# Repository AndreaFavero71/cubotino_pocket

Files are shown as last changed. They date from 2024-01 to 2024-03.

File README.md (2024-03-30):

# CUBOTino Pocket

This repo contains the relevant files for ....

How to make CUBOTino Pocket: A small, 3D printed, optimal solver for 2x2x2 Rubik's cube
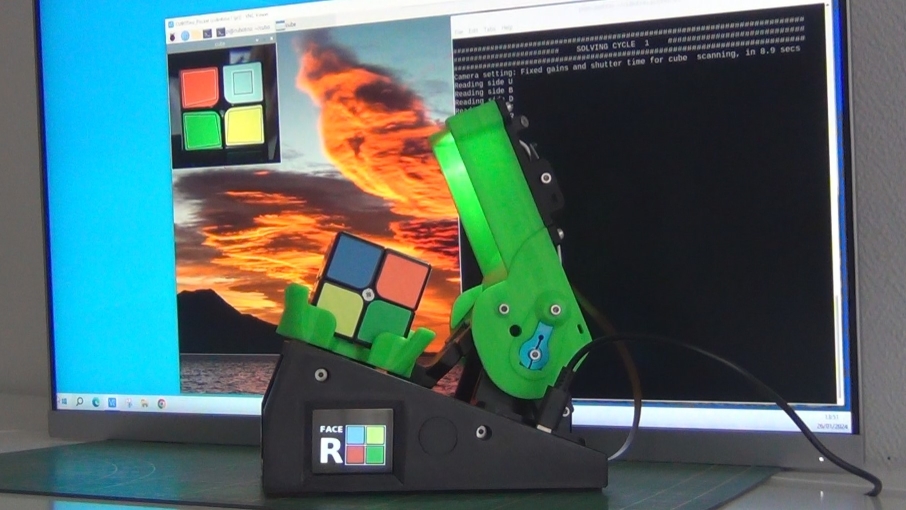
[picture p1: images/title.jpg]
title image


Further robot info at: https://www.instructables.com/CUBOTino-Pocket-Optimal-Solver-Robot-for-Rubiks-Cu/

An impression of the robot: https://youtu.be/wB4MwINGon0

This git repo simplifies the download of the individual files and automates as much a possible the deployment to the Raspberry Pi

This installation has proved to work on different Raspberry Pi models; Please report in case you experience issues.

# How to use it:
1. Flash your SD card according to the procedure in the [document here](doc/How_to_make_CUBOTino_Pocket_20240329.pdf) , Chapter 7, Step1 to Step3
2. Put the sd card in the pi and power it. You can monitor the boot process if you connect an hdmi monitor to it but it is not essential. 
3. Try to connect to the Raspberry Pi via SSH. On Windows you can use Putty. On linux and mac you can type directly:
```
ssh pi@cubotino.local
```
4. If you can't reach the pi like this, you will have to scan your network to find the IP to use
5. After you are connected via ssh, type the following commands in the shell:
```
git clone https://github.com/AndreaFavero71/cubotino_pocket.git
cd cubotino_pocket/src
chmod +x install/setup.sh
sudo ./install/setup.sh
```
6. Make sure the script runs without error until the end. It should ask you to reboot. Type 'y' and hit enter.
7. If the question "Reboot (y/n)" does't appear, them the installation is facing issues; Try to fix the errors, and run the script again.
8. If the question "Reboot (y/n) does appear, You should get the proper environment after the reboot.

# Build the robot:
Follow the instructions (saved at /doc folder)

# Tuning the servos position via GUI (via VNC):
```
cd ~/cubotino_pocket/src
source .virtualenvs/bin/activate
python Cubotino_P_GUI.py
```
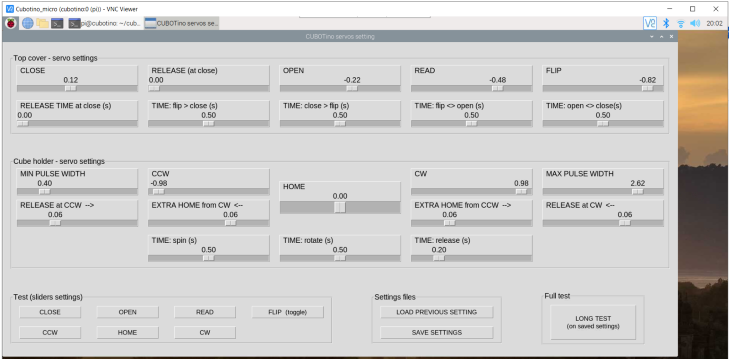
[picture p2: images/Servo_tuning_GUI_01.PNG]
title image


# Executing manually
From a shell, you can run the main python script like this:
```
cd ~/cubotino_pocket/src
source .virtualenvs/bin/activate
python Cubotino_P.py
```
of course, you can replace `Cubotino_P.py` by any other python scripts as mentioned in the documentation.

# Enabling autostart
When everything is tuned and you want to autostart the software automatically on reboot, just type :
```
    sudo crontab -e
```
select the nano editor '1' then go to the last line of the window and remove the first '#' character of the line . This uncomment the startup script that launches cubotino on startup. You can reboot after to test it.

# VNC connection
You can always connect with ssh. If you prefere VNC you can download the RealVNC client (this is the one I use). You just have that start it like this:
```
vncviewer cubotino.local
```
It will ask for the credential. Use 'pi' and the same password you use for ssh. You should have a desktop version in this way

Check out the "How_to_make ...  .pdf" document (at /doc folder) for further info.<br /><br />

# Please leave a feedback if you build it
I hope many of you will decide to build your own CUBOTino, and that you'll enjoy it as much much as I did. <br />
I hope you will also post an "I Made it", on the Instructables site of this project (link above); <br />
I can ensure you, seeing a new born CUBOTino makes me feel very well 🙂

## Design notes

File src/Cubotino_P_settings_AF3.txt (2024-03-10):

{
"frameless_cube": "auto",
"disp_width": "130",
"disp_height": "160",
"disp_offsetL": "-2",
"disp_offsetT": "0",
"camera_width_res": "640",
"camera_hight_res": "480",
"s_mode": "7",
"kl": "0.95",
"expo_shift": "-1.0",
"x_l": "46",
"x_r": "82",
"y_u": "32",
"y_b": "78",
"warp_fraction": "6.2",
"warp_slicing": "2.0",
"square_ratio": "1",
"rhombus_ratio": "0.3",
"delta_area_limit": "0.7",
"collage_w": "1024",
"marg_coef": "0.05",
"cam_led_bright": "0.1",
"detect_timeout": "40",
"show_time": "7",
"warn_time": "1.5",
"quit_time": "4.5",
"cover_self_close": "true",
"vnc_delay": "0.0",
"built_by": "",
"built_by_x": "25",
"built_by_fs": "16",
"fcs_delay": "3"
}

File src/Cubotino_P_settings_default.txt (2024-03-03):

{
"frameless_cube": "auto",
"disp_width": "130",
"disp_height": "160",
"disp_offsetL": "0",
"disp_offsetT": "0",
"camera_width_res": "640",
"camera_hight_res": "480",
"s_mode": "7",
"kl": "0.95",
"expo_shift": "-0.6",
"x_l": "0",
"x_r": "0",
"y_u": "0",
"y_b": "0",
"warp_fraction": "7",
"warp_slicing": "1.5",
"square_ratio": "1",
"rhombus_ratio": "0.3",
"delta_area_limit": "0.7",
"collage_w": "1024",
"marg_coef": "0.1",
"cam_led_bright": "0.1",
"detect_timeout": "40",
"show_time": "7",
"warn_time": "1.5",
"quit_time": "4.0",
"cover_self_close": "true",
"vnc_delay": "0.5",
"built_by": "",
"built_by_x": "25",
"built_by_fs": "16",
"fcs_delay": "3"
}

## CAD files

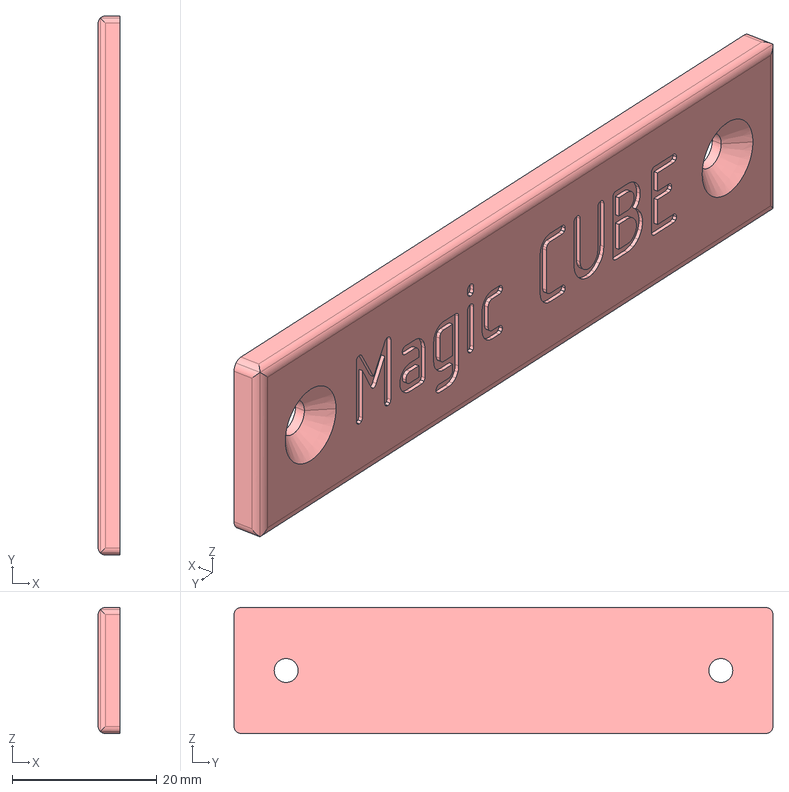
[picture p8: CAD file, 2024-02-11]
stp/Personaliz_plate_01.stp
3.00 x 74.4 x 17.4 mm

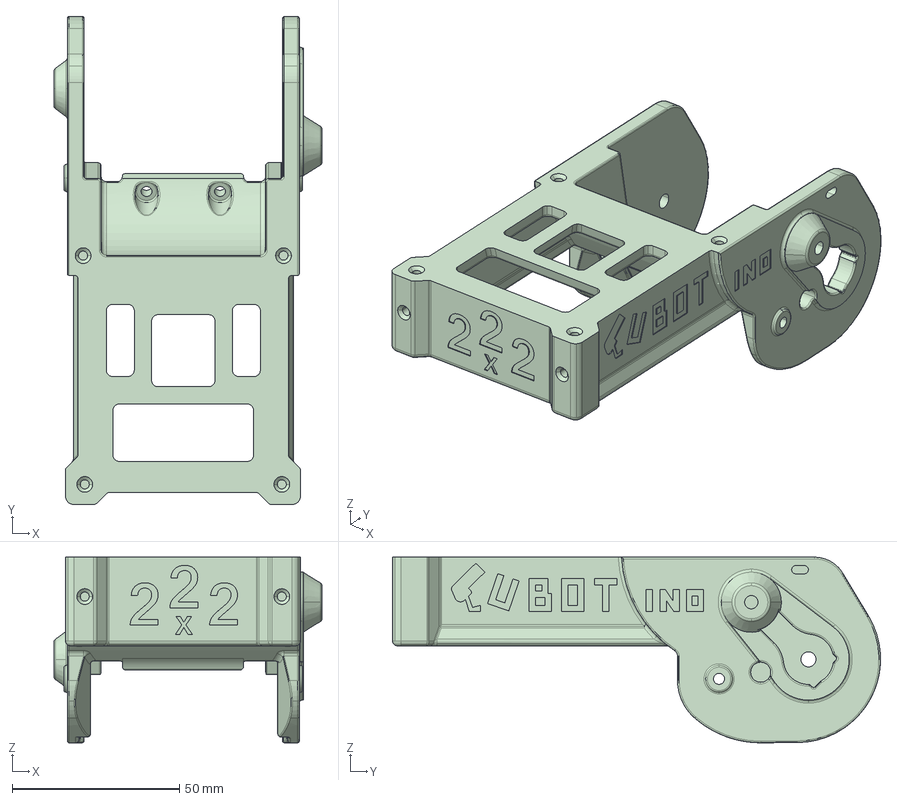
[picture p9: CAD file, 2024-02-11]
stp/Top_cover_pocket.stp
80.2 x 146.1 x 55.6 mm

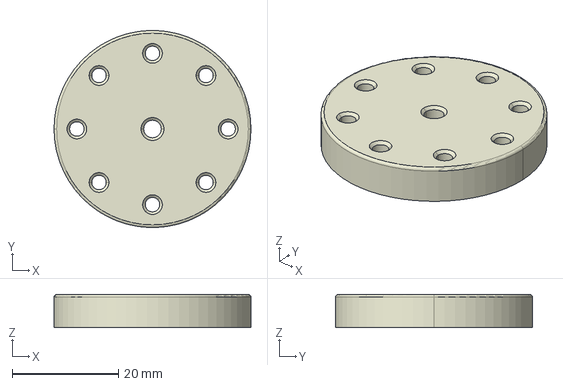
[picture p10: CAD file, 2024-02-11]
stp/Alternative_Servo_axis_sup_pocket.stp
37.0 x 37.0 x 6.20 mm

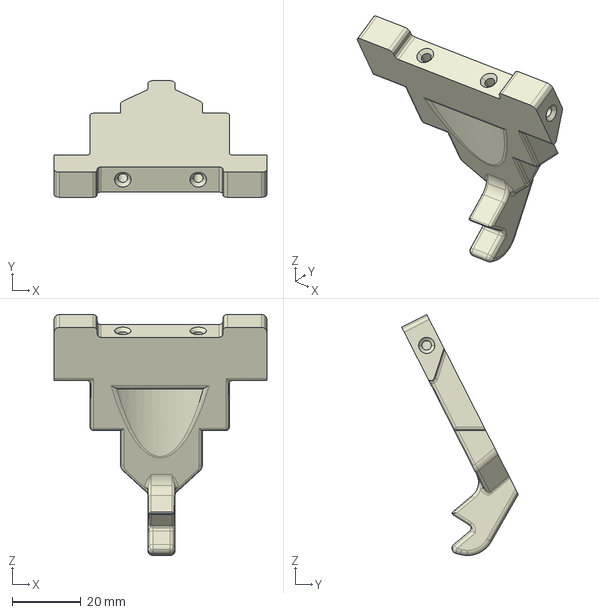
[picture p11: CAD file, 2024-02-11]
stp/Cube_lifter.stp
62.0 x 34.0 x 70.3 mm

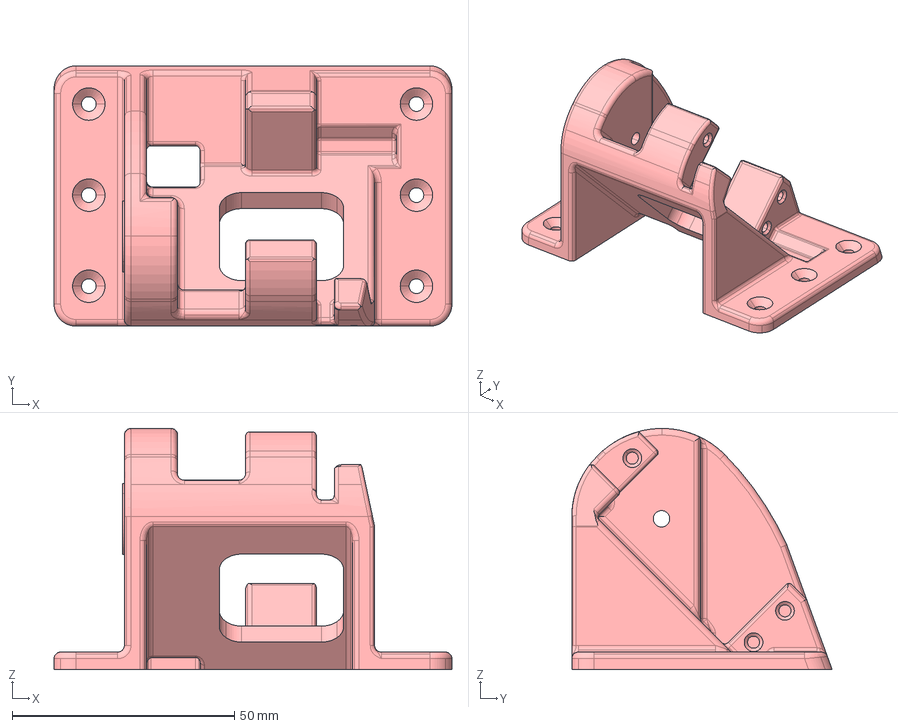
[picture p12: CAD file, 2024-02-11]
stp/Hinge_pocket.stp
89.6 x 58.6 x 54.3 mm

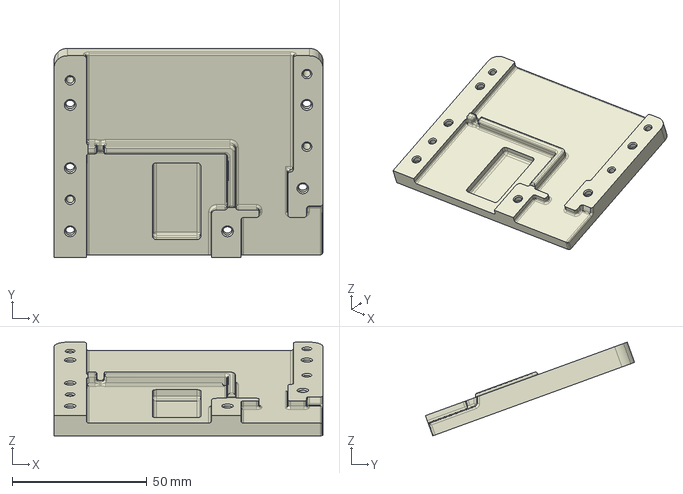
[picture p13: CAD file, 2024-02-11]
stp/Baseplate_rear.stp
100.0 x 77.8 x 34.8 mm

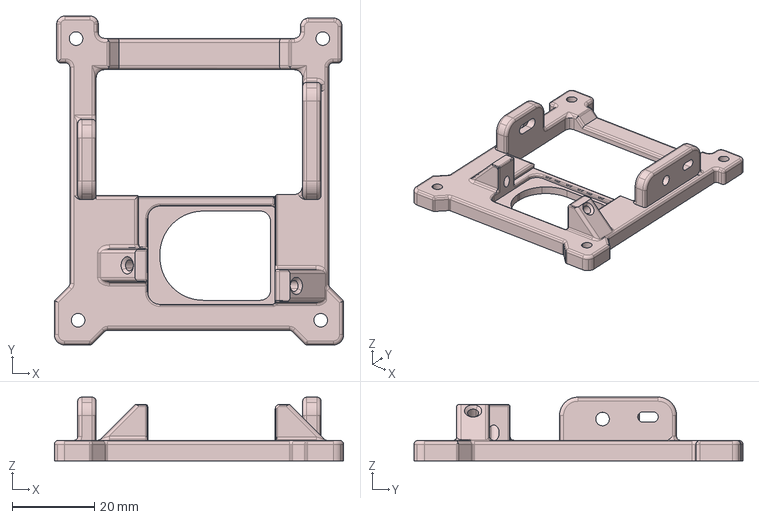
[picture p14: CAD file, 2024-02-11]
stp/PiCamera_holder_frame_pocket.stp
70.3 x 80.0 x 15.5 mm

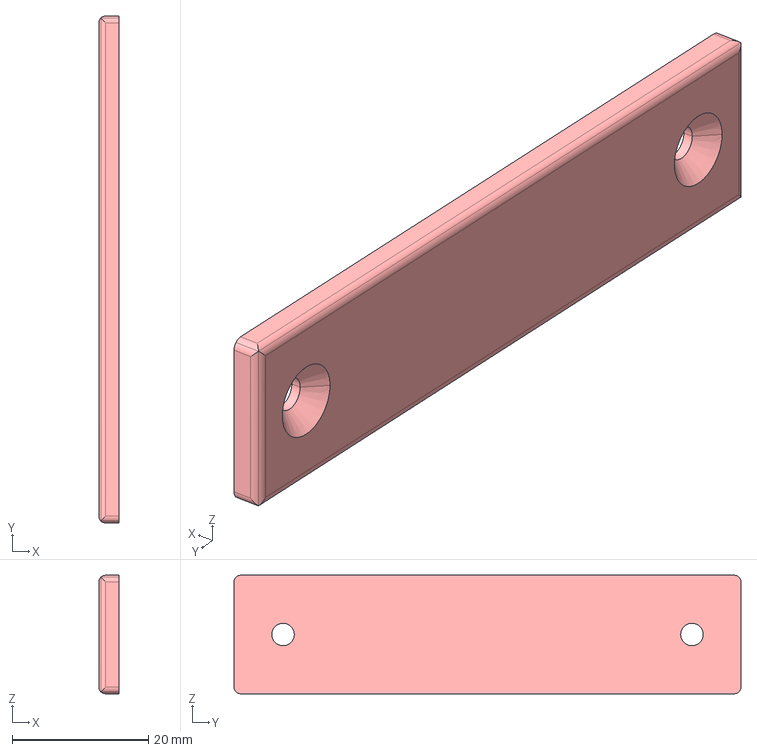
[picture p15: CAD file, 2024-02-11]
stp/Personaliz_plate.stp
3.00 x 74.4 x 17.4 mm

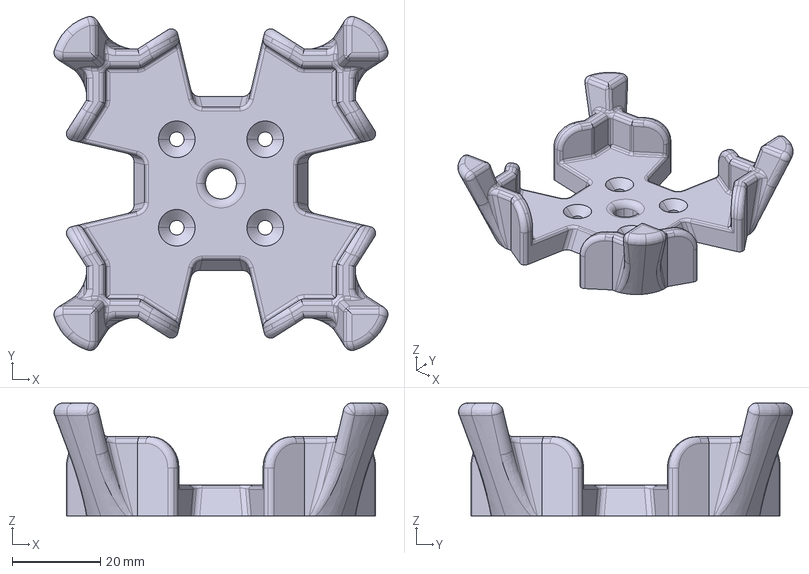
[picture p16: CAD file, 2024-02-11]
stp/Cube_holder_pocket.stp
75.9 x 75.9 x 25.7 mm

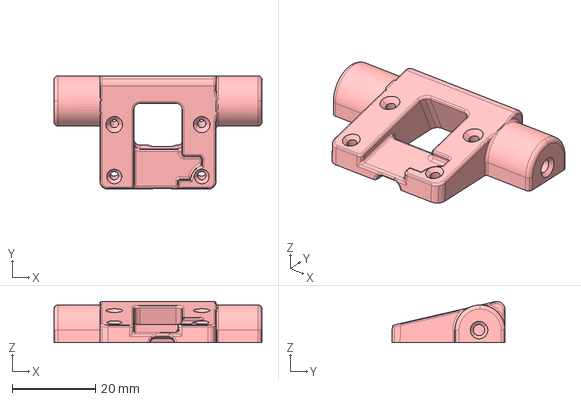
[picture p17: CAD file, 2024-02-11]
stp/PiCamera_holder_step.stp
50.0 x 27.3 x 9.88 mm

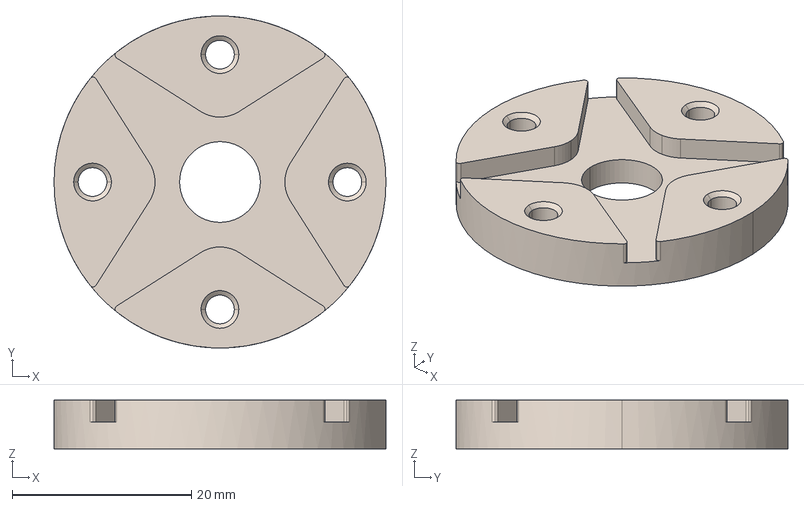
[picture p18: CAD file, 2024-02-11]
stp/Servo_axis_inf_pocket.stp
37.0 x 37.0 x 5.44 mm

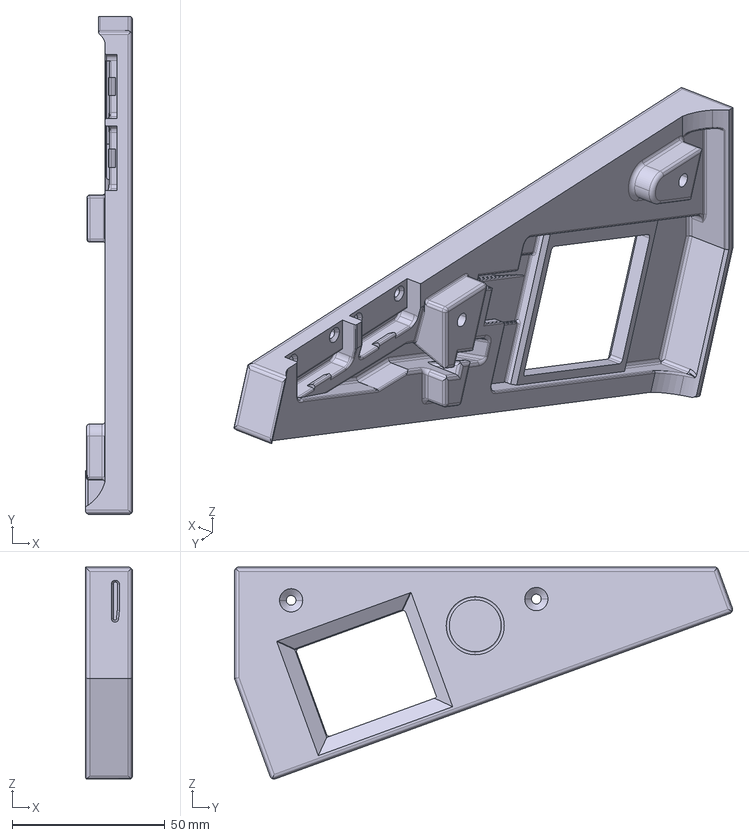
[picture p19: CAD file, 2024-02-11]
stp/PCB_cover_display_rev1.stp
15.5 x 163.0 x 69.4 mm

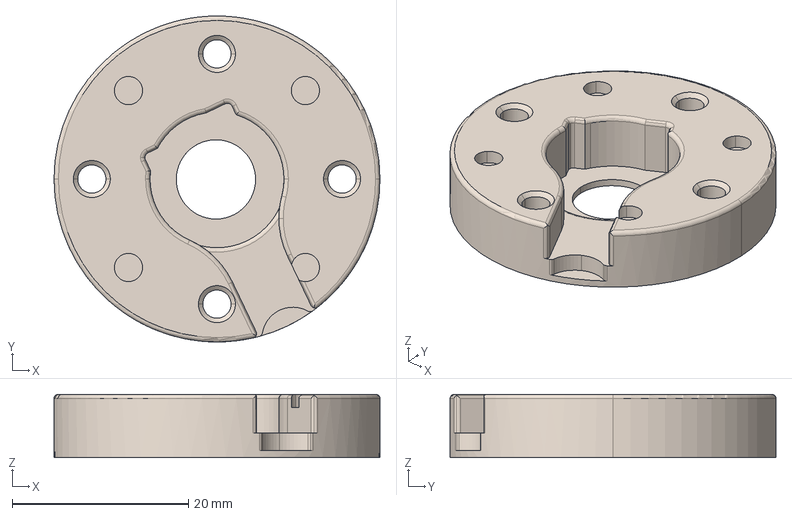
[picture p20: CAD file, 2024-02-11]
stp/Alternative_Servo_axis_inf_pocket.stp
37.0 x 37.0 x 7.20 mm

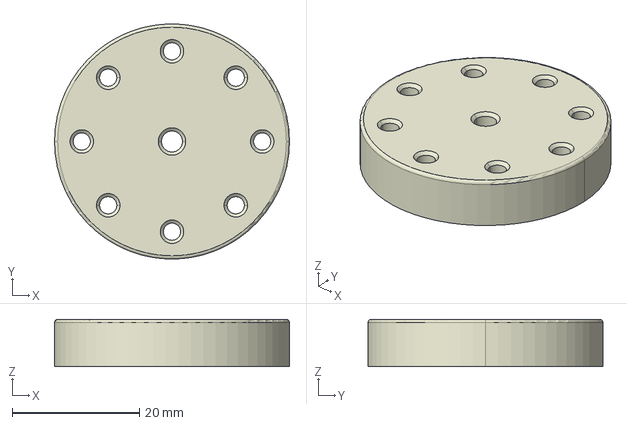
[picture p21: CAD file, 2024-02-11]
stp/Servo_axis_sup_pocket.stp
37.0 x 37.0 x 7.46 mm

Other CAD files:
stp/Structure_pocket.stp
stp/Baseplate_front.stp
stp/PCB_cover_display_UsbC.stp
stl/Alternative_Servo_axis_inf_pocket..stl
stl/Alternative_Servo_axis_sup_pocket..stl
stl/Baseplate_rear.stl
stl/Cube_lifter.stl
stl/Personaliz_plate.stl
stl/Personaliz_plate_01.stl
stl/Servo_axis_inf_pocket..stl
stl/Servo_axis_sup_pocket..stl

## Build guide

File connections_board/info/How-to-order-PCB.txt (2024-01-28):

How to Order PCB

Please refer to:
https://docs.easyeda.com/en/PCB/Order-PCB

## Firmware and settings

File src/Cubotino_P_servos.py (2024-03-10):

#!/usr/bin/python
# coding: utf-8

"""
#############################################################################################################
# Andrea Favero, 10 March 2024
#
# This code relates to CUBOTino Pocket, a very small and simple Rubik's cube solver robot 3D printed.
# CUBOTino_P is the autonomous version of the CUBOTino robot series, for the 2x2x2 Rubik's cube.
# This specific script controls two servos based on the movements string from Cubotino_P.py
# 
# Possible moves with this robot
# 1) Spins the complete cube ("S") laying on the bottom face: 1 means CW 90deg turns, while 3 means 90CCW turn
# 2) Flips the complete cube ("F") by "moving" the Front face to Bottom face: Only positive values are possible
# 3) Rotates the bottom layer ("R") while costraining the 2nd and 3rd layer.
# 4) The order of S, F has to be strictly followed
# 5) Example 'F1R1S3' means: 1x cube Flip, 1x (90deg) CW rotation of the 1st (Down) layer, 1x (90deg) CCW cube Spin
#
# For Rotations, the bottom servo makes a little extra rotation than target, before coming back to target; This
# recovers the gaps between cube_hoder - cube - top_cover, and still getting to a decent cube layers alignment.
#
#############################################################################################################
"""



##################    imports standard libraries   #################################
import time                            # import time library
import RPi.GPIO as GPIO                # import RPi GPIO library
GPIO.setmode(GPIO.BCM)                 # setting GPIO pins as "Broadcom SOC channel" number, these are the numbers after "GPIO"
GPIO.setwarnings(False)                # setting GPIO to don't return allarms
from gpiozero import Servo, PWMLED     # import modules for the PWM part
# ##################################################################################



##################    GPIO pins for Servos and LED   ###############################
t_servo_pin = 12                # GPIO pin used for the top servo
b_servo_pin = 13                # GPIO pin used for the bottom servo
top_cover_led_pin = 18          # GPIO pin used to control the LED on/off
# ##################################################################################



##################    general servo_settings    ####################################
robot_init_status=False         # boolean to track the servos inititialization status
stop_servos=True                # boolean to stop the servos during solving proces: It is set true at the start, servos cannot operate
b_servo_operable=False          # variable to block/allow bottom servo operation
fun_status=False                # boolean to track the robot fun status, it is True after solving the cube :-)
s_debug=False                   # boolean to print out info when debugging
flip_to_close_one_step = False  # f_to_close steps (steps from flip up to close) is set false (=2 steps)
led_init_status = False         # boolean to track the led (PWM) inititialization status
# ##################################################################################





def init_top_cover_led():
    global factory
    from gpiozero.pins.pigpio import PiGPIOFactory    # pigpio library is used, to use hardare timers on PWM (to avoid servo jitter)
    factory = PiGPIOFactory()                         # pin factory setting to use hardware timers, to avoid servo jitter
    
    # NOTE: High freq. on the led PWM prevents camera from seeing flickering
    top_cover_led = PWMLED(top_cover_led_pin,
                           active_high=True,
                           initial_value=0,
                           frequency=5000000,
                           pin_factory=factory)
    
    led_init_status = True
    return led_init_status, top_cover_led




def load_servos_parameters(print_out):
    """ Parameters are imported from a json file, to make easier to list/document/change the variables
        that are expected to vary on each robot.
        These servo_settings are under a function, instead of root, to don't be executed when this script is used from CLI
        with arguments; In this other case the aim is to help setting the servo to their mid position."""
    
    from Cubotino_P_settings_manager import settings as settings   # custom library managing the settings from<>to the settings files
    
    global t_servo, t_min_pulse_width, t_max_pulse_width, t_top_cover                       # top servo, pulse width, status
    global t_servo_close, t_servo_open, t_servo_read, t_servo_flip, t_servo_rel             # top servo related angles and status
    global t_flip_to_close_time, t_close_to_flip_time, t_flip_open_time, t_open_close_time, t_rel_time  # top servo timers
    
    global b_servo, b_min_pulse_width, b_max_pulse_width                                    # bottom servo and pulse width
    global b_servo_CCW, b_servo_CW, b_home, b_rel_CW, b_rel_CCW, b_extra_home_CW, b_extra_home_CCW   # bottom servo angles
    global b_servo_CCW_rel, b_servo_CW_rel, b_home_from_CCW, b_home_from_CW                 # bottom servo calculated angles
    global b_servo_home, b_servo_stopped, b_servo_CW_pos, b_servo_CCW_pos                   # bottom servo status
    global b_spin_time, b_rotate_time, b_rel_time                                           # bottom servo timers
    

    servo_settings = settings.get_servos_settings()  # settings are retrieved from the settings Class

    if print_out:                                # case print_out variable is set true
        fname = settings.get_servo_settings_fname() # settings filename is retrieved
        print('\nImporting servos settings from the text file:', fname)    # feedback is printed to the terminal
        print('\nImported parameters: ')         # feedback is printed to the terminal
        for param, s in servo_settings.items():  # iteration over the settings dict
            print(f"{param}: {s}")               # feedback is printed to the terminal
        print()
          
    try:
        t_min_pulse_width = servo_settings['t_min_pulse_width']        # defines the min Pulse With the top servo reacts to
        t_max_pulse_width = servo_settings['t_max_pulse_width']        # defines the max Pulse With the top servo reacts to
        t_servo_close = servo_settings['t_servo_close']                # Top_cover close position, in gpiozero format
        t_servo_open = servo_settings['t_servo_open']                  # Top_cover open position, in gpiozero format
        t_servo_read = servo_settings['t_servo_read']                  # Top_cover camera read position, in gpiozero format
        t_servo_flip = servo_settings['t_servo_flip']                  # Top_cover flip position, in gpiozero format
        t_servo_rel_delta = servo_settings['t_servo_rel_delta']        # Top_cover release angle movement from the close position to release tension
        t_flip_to_close_time = servo_settings['t_flip_to_close_time']  # time for Top_cover from flip to close position
        t_close_to_flip_time = servo_settings['t_close_to_flip_time']  # time for Top_cover from close to flip position 
        t_flip_open_time = servo_settings['t_flip_open_time']          # time for Top_cover from open to flip position, and viceversa  
        t_open_close_time = servo_settings['t_open_close_time']        # time for Top_cover from open to close position, and viceversa
        t_rel_time = servo_settings['t_rel_time']                      # time for Top_cover to release tension from close position

        b_min_pulse_width = servo_settings['b_min_pulse_width']        # defines the min Pulse With the bottom servo reacts to
        b_max_pulse_width = servo_settings['b_max_pulse_width']        # defines the max Pulse With the bottom servo reacts to
        b_servo_CCW = servo_settings['b_servo_CCW']                    # Cube_holder max CCW angle position
        b_servo_CW = servo_settings['b_servo_CW']                      # Cube_holder max CW angle position
        b_home = servo_settings['b_home']                              # Cube_holder home angle position
        b_rel_CCW = servo_settings['b_rel_CCW']                        # Cube_holder release angle from CCW angle positions, to release tension
        b_rel_CW = servo_settings['b_rel_CW']                          # Cube_holder release angle from CW angle positions, to release tension
        b_extra_home_CW = servo_settings['b_extra_home_CW']            # Cube_holder release angle from home angle positions, to release tension
        b_extra_home_CCW = servo_settings['b_extra_home_CCW']          # Cube_holder release angle from home angle positions, to release tension
        b_spin_time = servo_settings['b_spin_time']                    # time for Cube_holder to spin 90 deg (cune not contrained)
        b_rotate_time = servo_settings['b_rotate_time']                # time for Cube_holder to rotate 90 deg (cube constrained)
        b_rel_time = servo_settings['b_rel_time']                      # time for Cube_holder to release tension at home, CCW and CW positions
        
        
    except:   # exception will be raised if json keys differs, or parameters cannot be converted to float
        print('Error on converting to float the imported parameters (at Cubotino_T_servos.py)')   # feedback is printed to the terminal                                  
        return robot_init_status                                        # return robot_init_status variable, that is False
    
    # bottom servo derived positions
    b_servo_CCW_rel = round(b_servo_CCW + b_rel_CCW,3)      # bottom servo position to rel tensions when fully CW
    b_servo_CW_rel = round(b_servo_CW - b_rel_CW,3)         # bottom servo position to rel tensions when fully CCW
    b_home_from_CW = round(b_home - b_extra_home_CW,3)      # bottom servo extra home position, when moving back from full CW
    b_home_from_CCW = round(b_home + b_extra_home_CCW,3)    # bottom servo extra home position, when moving back from full CCW
    
    # top servo derived position
    t_servo_rel = round(t_servo_close - t_servo_rel_delta,3) # top servo position to release tension
    
    timer = {}                                              # dict to store the servos timer values
    timer['t_flip_to_close_time'] = t_flip_to_close_time 
    timer['t_close_to_flip_time'] = t_close_to_flip_time
    timer['t_flip_open_time'] = t_flip_open_time
    timer['t_open_close_time'] = t_open_close_time
    if t_servo_rel < t_servo_close:                         # case the t_servo_rel_delta is > zero
        timer['t_rel_time'] = t_rel_time
    else:
        timer['t_rel_time'] = 0
    timer['b_spin_time'] = b_spin_time
    timer['b_rotate_time'] = b_rotate_time
    timer['b_rel_time'] = b_rel_time                                
    
    return timer   # return robot timers






def init_servo(print_out=s_debug, start_pos=0, f_to_close_mode=False, s_silent=False):
    """ Function to initialize the robot (servos position) and some global variables, do be called once, at the start."""
    
    global robot_init_status, fun_status, flip_to_close_one_step, led_init_status, top_cover_led
    global flip_to_close_one_step
    
    set_display()
    
    if s_silent and not led_init_status:      # case s_silent is se True
        led_init_status, top_cover_led = init_top_cover_led()  # the GPIO for the led is initialized
        timer = load_servos_parameters(print_out)  # upload the servos parameters
        robot_init_status = True              # robot_init_status is set True
        return robot_init_status, timer       # the function returns initi status and timer
        
        
    if not led_init_status:                   # case the led_init_status variable is false
        led_init_status, top_cover_led = init_top_cover_led()  # the GPIO for the led is initialized
 
    
    if not robot_init_status and not s_silent:  # case the inititialization status of the servos false
        
        from Cubotino_P_pigpiod import pigpiod as pigpiod # start the pigpiod server
        
        if f_to_close_mode:                   # case the init got the f_to_close_mode as true
            flip_to_close_one_step = True     # flip_to_close_one_step is set true
        
        timer = load_servos_parameters(print_out)  # upload the servos parameters  
        if len(timer) == 0:                   # case the return is an empty dict
            print('Could not find Cubotino_P_servo_settings.txt')  # feedback is printed to the terminal                                  
            return robot_init_status          # return robot_init_status variable, that is False
        
        if start_pos==0:     # case the servos initial position equals zero (very first setting)
            t_servo = t_servo_create(t_min_pulse_width, t_max_pulse_width)  # t_servo servo object creation
            b_servo = b_servo_create(b_min_pulse_width, b_max_pulse_width)  # b_servo servo object creation                 
        else:                # case the servos initial position differes from zero
            t_servo = t_servo_create(t_min_pulse_width, t_max_pulse_width, t_servo_open)  # t_servo servo object creation
            b_servo = b_servo_create(b_min_pulse_width, b_max_pulse_width, b_home)        # b_servo servo object creation

        t_top_cover = start_pos               # variable to track the top cover/lifter position              
        b_servo_home=True                     # boolean of bottom servo at home
        b_servo_stopped = True                # boolean of bottom servo at location the lifter can be operated
        b_servo_CW_pos=False                  # boolean of bottom servo at full CW position
        b_servo_CCW_pos=False                 # boolean of bottom servo at full CCW position
        
        robot_init_status = True              # boolean to track the inititialization status of the servos is set true
        if print_out:                         # case the print_out variable is set true
            print("\nServo init done")        # feedback is printed to the terminal
        
        if start_pos !=0:                     # case the start_pos is not zero
            servo_start_pos(start_pos)        # servos are positioned to the start position    
        fun_status=False                      # boolean to track the robot fun status, it is True after solving the cube :-)
        cam_led_test()                        # makes a very short led test
        cam_led_Off()                         # forces the led off
        
        return robot_init_status, timer       # returns the init status and the timer(s) values
    
    else:                                     # caase robot_init_status already True
        return True                           # confirms the init status, and don't return thetimer






def t_servo_create(t_min_pulse_width, t_max_pulse_width, initial_pos=0):
    """top servo object creation."""
    global t_servo_pin, factory, t_servo
    
    try:                          # tentative
        t_servo                   # name of t_servo
        t_servo.close()           # t_servo object is eliminated
    except NameError:             # case a name error exception is raised
        pass
    
    t_servo = Servo(t_servo_pin,                                 # GPIO pin associated to the top servo
                    initial_value = initial_pos,                 # Top_cover positioned to initial_pos
                    min_pulse_width = t_min_pulse_width/1000,    # min Pulse Width the top servo reacts to
                    max_pulse_width = t_max_pulse_width/1000,    # max Pulse Width the top servo reacts to
                    frame_width=0.020,                           # min pulse width variation aceepted
                    pin_factory=factory)                         # way to use hardware based timers for the PWM
    
    time.sleep(0.7)          # time to let the servo reaching the initial_value angle
    return t_servo





def b_servo_create(b_min_pulse_width, b_max_pulse_width, initial_pos=0):
    """bottom servo object creation."""
    global b_servo_pin, factory, b_servo

    try:                          # tentative
        b_servo                   # name of b_servo
        b_servo.close()           # b_servo object is eliminated
    except NameError:             # case a name error exception is raised
        pass
    
    b_servo = Servo(b_servo_pin,                                # GPIO pin associated to the bottom servo
                    initial_value = initial_pos,                 # Cube_holder positioned to initial_pos
                    min_pulse_width = b_min_pulse_width/1000,    # min Pulse Width the bottom servo reacts to
                    max_pulse_width = b_max_pulse_width/1000,    # max Pulse Width the bottom servo reacts to
                    frame_width=0.020,                           # min pulse width variation aceepted
                    pin_factory=factory)                         # way to used hardware based timers for the PWM
    
    time.sleep(0.7)          # time to let the servo reaching the initial_value angle
    return b_servo







def set_display():
    global s_disp
    
    from Cubotino_P_display import display as s_disp    
    s_disp.set_backlight(0)     # display backlight is set off
    s_disp.show_cubotino()      # show cubotino logo on display, when this script is imported
    s_disp.set_backlight(1)     # activates the display backlight





def servo_tune_via_gui(debug, start_pos):
    
    global robot_init_status, stop_servos, b_servo_operable, s_debug
    
    robot_init_status=False        # boolean to track the servos inititialization status
    s_debug=debug                  # boolean to print out info when debugging
    robot_init_status = init_servo(s_debug, start_pos)
    stop_servos=False              # boolean to stop the servos during solving proces: It is set true at the start, servos cannot operate
    b_servo_operable=True          # variable to block/allow bottom servo operation
    return robot_init_status
    







def quit_func():
    """ Sets the used GPIO as output, and force them to low. This wants to prevent servos to move after closing the script."""
    
    GPIO.setup(top_cover_led_pin, GPIO.OUT, initial=GPIO.LOW)   # GPIO top_cover_led_pin (Top_cover_Led) is set as output, and force low
    GPIO.setup(t_servo_pin, GPIO.OUT, initial=GPIO.LOW)         # GPIO t_servo_pin (Top_cover servo) is set as output, and force low
    GPIO.setup(b_servo_pin, GPIO.OUT, initial=GPIO.LOW)         # GPIO b_servo_pin (Cube_holder servo) is set as output, and force low






def cam_led_On(value=0.05):
    """ Sets the top_cover led ON, with brightness in arg. Value ranges from 0 to 0.3"""
    
    if value >= 0.3:                              # case arg is bigger than, or equal to 0.3
        top_cover_led.value = 0.3                 # top cover led PWM is set to 30%
    else:                                         # case arg is smaller than 0.3
        top_cover_led.value = value               # top cover led PWM is set to arg value






def cam_led_Off():
    """ Sets the top_cover led OFF."""
    top_cover_led.off()      # top cover led PWM is set to 0






def cam_led_test():
    """ Fade the led On and Off at the init, to show the led worwing."""
    
    for i in range(0,32,4):            # iterates from 0 to 28 in steps of 4 
        top_cover_led.value = i/100    # top cover led PWM is set iterator %
        time.sleep(0.02)               # very short time sleep
    
    for i in range(28,-4,-4):          # iterates from 28 to 0 in steps of -4 
        top_cover_led.value = i/100    # top cover led PWM is set iterator %
        time.sleep(0.02)               # very short time sleep
    
    top_cover_led.off()                # top cover led PWM is set to 0
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

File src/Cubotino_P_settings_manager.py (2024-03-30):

#!/usr/bin/python
# coding: utf-8

"""
#############################################################################################################
#  Andrea Favero 29 March 2024
#
# This code relates to CUBOTino 2x2x2 (Pocket), a very small and simple Rubik's cube solver robot 3D printed.
# CUBOTino_P is the autonomous version of the CUBOTino robot series, for the 2x2x2 Rubik's cube.
# This specific script manages the interactions with the settings files (json text files).
#
# Parameters at the settings files are those more likely to vary between differentt robots.
# Having the setting "insulated" in text files makes easier to list, document, change them.
#
# Mac address is used to match boards and settings on my robots: This limits mistakes at my end. 
#
#############################################################################################################
"""

import sys, glob, os.path, pathlib, json
from getmac import get_mac_address           # library to get the device MAC ddress


class Settings:

    def __init__(self):
        """Check if local settings exist, if not are created.
            Reads the local settings files.
            Parameters and settings are imported.
            Settings datatypes are parsed."""
        
        # mac address is used by myself (Andrea Favero), to upload the settings fitting my robot
        self.folder = pathlib.Path().resolve()            # active folder (should be home/pi/cubotino_pocket/src)
        self.macs_AF = self.get_macs_AF(self.folder)      # mac addresses of AF bots are retrieved
        self.eth_mac = get_mac_address().lower()          # mac address of the Pi board is retrieved
        
        self.check_local_settings()                       # checks whether local settings files exist
        
        s = self.read_settings()                          # reads the general robot settings
        servos_s = self.read_servos_settings()            # reads the servos settings
        
        self.s = self.parse_settings(s)                   # converts settings to correct datatype
        self.servos_s = self.parse_servos_settings(servos_s) # converts servos settings to correct datatype



    def get_macs_AF(self, folder):
        """Returns a tuple with the mac adresses from a text file (macs_AF.txt)."""
        
        fname = os.path.join(folder,'macs_AF.txt')        # filename for the text file with listed the mac adrresses
        macs_AF = []                                      # emppty list to store the mac addresses
        if os.path.exists(fname):                         # case the servo_settings file exists
            with open(fname, "r") as f:                   # file is opened in reading mode
                macs = f.readlines()                      # text lines are retrieved
                for mac in macs:                          # iteration over the lines
                    macs_AF.append(mac.lower().strip())   # stripped lines contents are appended to the mac list
        
        # in case the file is missed the returned tuple is empty
        return tuple(macs_AF)                             # list is converted to tuple and returned



    def get_fname_AF(self, fname, pos):
        """Generate settings filenames for AF robot."""
        return fname[:-4] + '_AF' + str(pos+1) + '.txt'




    def check_local_settings(self):
        """Check the presence of local settings, If not present, the default settings files
            are copied as local settings files."""
        
        fnames_default = ('Cubotino_P_settings_default.txt' , 'Cubotino_P_servo_settings_default.txt')
        fnames_local = ('Cubotino_P_settings.txt', 'Cubotino_P_servo_settings.txt')
        
        for i in range(2):
            fname = fnames_local[i]                               # file name to locally save general settings
            
            if self.eth_mac in self.macs_AF:                      # case the script is running on AF (Andrea Favero) robot
                pos = self.macs_AF.index(self.eth_mac)            # mac address row position in macs_AF.txt file
                fname = self.get_fname_AF(fname, pos)             # AF robot settings file name
            else:                                                 # case the script is not running on AF (Andrea Favero) robot
                fname = os.path.join(self.folder,fname)           # folder and file name for the settings, to be tuned
            
            if not os.path.exists(fname):                         # case the local settings file does not exist
                fname_d = os.path.join(self.folder,fnames_default[i]) # folder and file name for the settings, to be tuned
                
                if not os.path.exists(fname_d):                   # case the default settings file does not exist
                    print("\n\n\n")                               # print empty lines
                    print("#"*86)                                 # print a separation line
                    print(f"Missed file {fnames_default[0]}  or  {fnames_default[1]}") # feedback is printed to the terminal
                    print("Double check the wastebacket if these files were erared by mistake.") # feedback is printed to the terminal
                    print("These files are anyhow available at GitHub project page") # feedback is printed to the terminal
                    print("#"*86, "\n\n\n")                       # print a separation line
                    sys.exit(1)                                   # script is quitted with error
                
                with open(fname_d, 'r') as input:                 # default settings file is opened as input
                    output = open(fname, 'w')                     # local settings file is opened to be written
                    output.write(input.read())                    # default settings are saved into the local settings file
                
                print(f"One time action: Creating local settings file {fname}")  # feedback is printed to the terminal





    def get_settings(self):
        """Returns the general robot settings dict."""
        return self.s





    def get_servos_settings(self):
        """Returns the servos settings dict."""
        return self.servos_s
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

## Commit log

2024-01-30 Updated 3D files
    [Alternative_Servo_axis_inf_Pocket.stl, Alternative_Servo_axis_inf_pocket..stl, Alternative_Servo_axis_sup_Pocket.stl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]
2024-02-11 stp file
    Correct error: Previously, stl file were copied in this folder
    [Alternative_Servo_axis_inf_pocket..stl, Alternative_Servo_axis_inf_pocket..stp, Alternative_Servo_axis_sup_pocket..stl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]
2024-02-13 Renamed some files (removed double dot)
    [Alternative_Servo_axis_inf_pocket.stp, Alternative_Servo_axis_sup_pocket.stp, Cube_holder_pocket.stp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]
2024-02-22 Update Cubotino_P_display.py
    Solved a bug when pillow>=9.5
    [Cubotino_P_display.py]
2024-03-10 Improved settings management
    Local settings won't be overwritten when 'git pull'.
    Rationalized the settings management.
    [Cubotino_P_GUI.py, Cubotino_P_camera_os10.py, Cubotino_P_camera_os11.py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]
2024-03-14 Solved bug from previous commit
    Sliders update weren't saved to Cubotino_m_servo_settings.txt
    [Cubotino_P_GUI.py]
2024-03-14 Solved bug from previous commit
    Moving from Camera setting window to Servos setting window, most of the buttons are disabled. Forcing Open or Close enables all widgets
    [Cubotino_P_GUI.py]
2024-03-14 Solved bug from previous commit
    Preventing older characteres at file-end, when saving less content in *settings.txt
    [Cubotino_P_settings_manager.py]
